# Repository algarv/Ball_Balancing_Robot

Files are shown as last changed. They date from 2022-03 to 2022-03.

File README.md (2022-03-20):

# Ball_Balancing_Robot

For my winter quarter independent study project, set out to build my own version of a BallBot, a dynamically stable / statically unstable robot. I am designed my bot from CAD to control algorithm, utilizing 3D printing, laser cutting, and C programming on an RP2040 microcontroller. 

final

https://youtu.be/7S1Z_5BLMUo

### Hardware
* RP2040 ThingPlus Microcontroller 
* MPU6050 Stepper Motor Driver (x3)
* A4988 Stepper Motor Driver (x3)
* NEMA 17 Stepper Motors (x3) 

### Chassis Design
The chassis was built with a combination of 3D printed components and laser cut plates.
In addition to self-fabricated pieces, the following components were purchased:
* 2-3/8" Diameter x 1" Wide Omnidirectional Wheels from McMaster-Carr (https://www.mcmaster.com/2289T514/)
* 4-40 Aluminum threaded rodd
* 4-40 Hex Nuts
* 4-40 Hex Screws
* Rubber Washers (0.190" ID, 1/2" OD)

<p float="left">
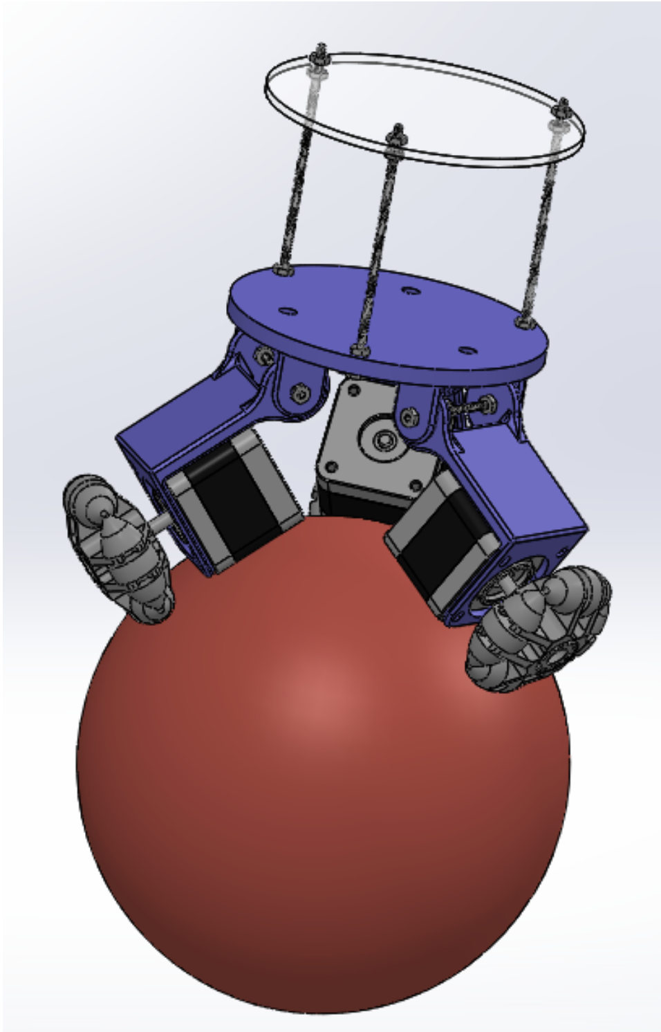
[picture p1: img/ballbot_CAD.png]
  
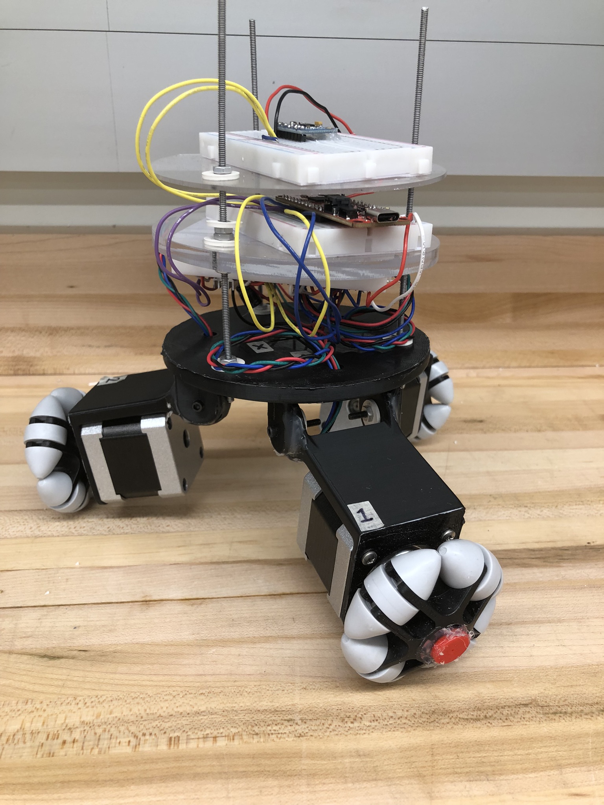
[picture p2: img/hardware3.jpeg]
   
</p>

### Electronics Assembly
The circuit was spread across three small breadboards, with an external power supply providing 8.5 volts to the motor drivers and a laptop providing 3.3V to the micocontroller. In future iteration, the power source would ideally be a battery with a volage regulator supplying both motor and logic power.

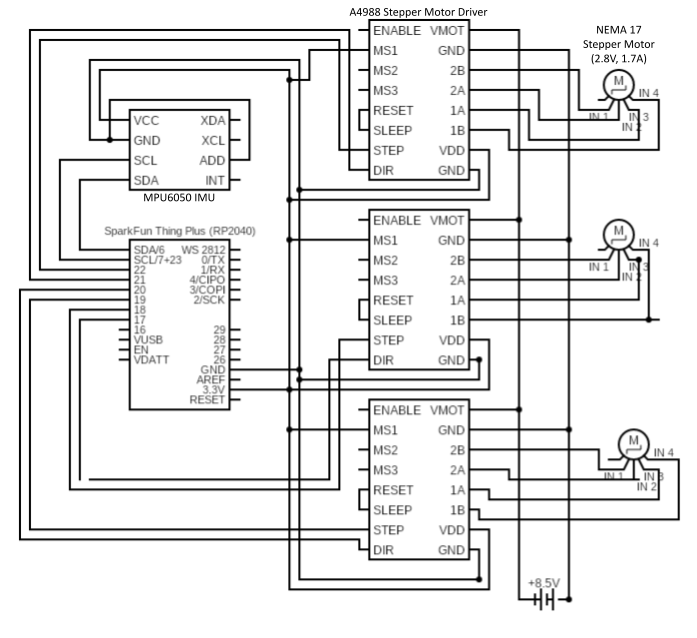
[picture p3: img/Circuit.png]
Circuit


### Controls
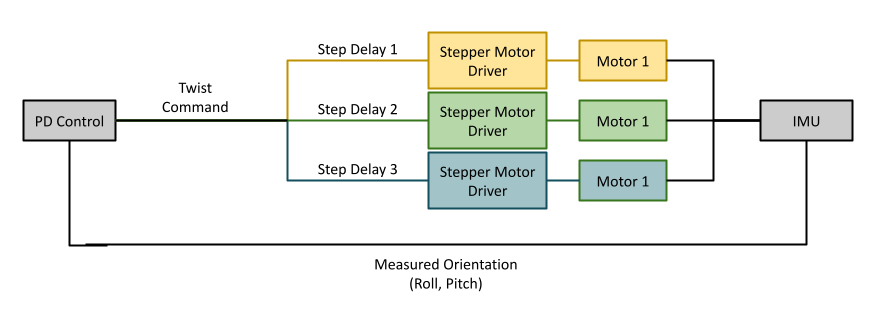
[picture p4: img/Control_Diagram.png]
Controls


The provided code demonstrates a PD feedback loop in which the IMU samples accelerometer and gyroscope data, uses a rolling average followed by a complimentary filter to calculate roll and pitch, and then generates a desired x and y velocity based on the deviation from 0. The IMU is initially calibrated such that 0 pitch and 0 roll can be considered a stable, upright system. The controll loop runs on a 500 Hz timer with the IMU sampled every 100 ms. The optimal Kp and Kd were found to be .29 and .27 respectively, however, these will likely vary depending on a variety of factors unique to each build. 

The software is based on the Pico SDK, find the documentation and instructions to get started here:
https://datasheets.raspberrypi.com/pico/raspberry-pi-pico-c-sdk.pdf

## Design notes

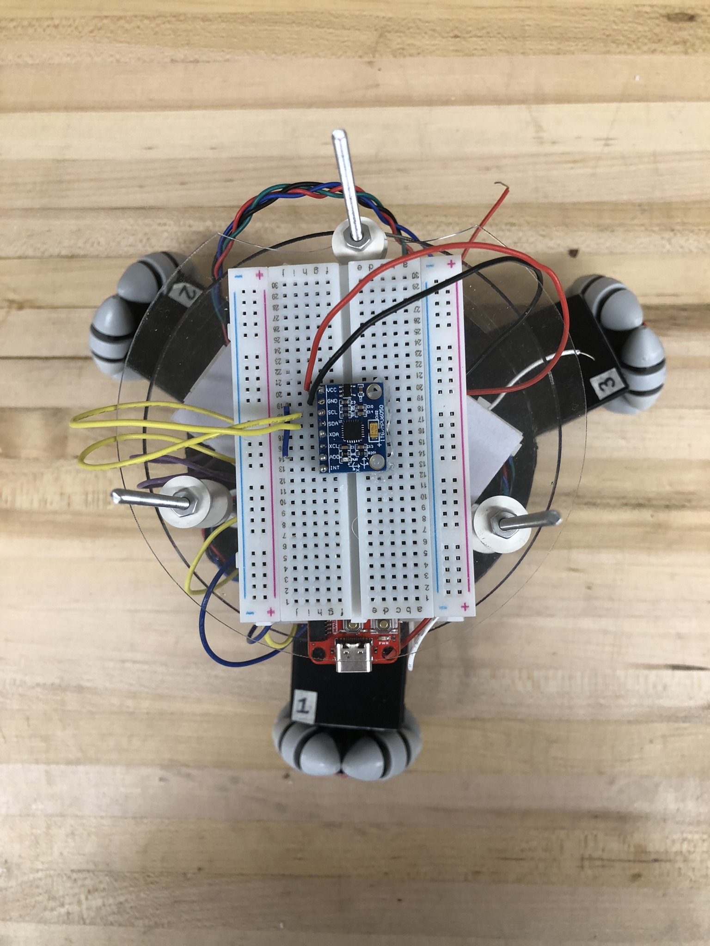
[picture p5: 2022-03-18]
img/hardware2.jpeg

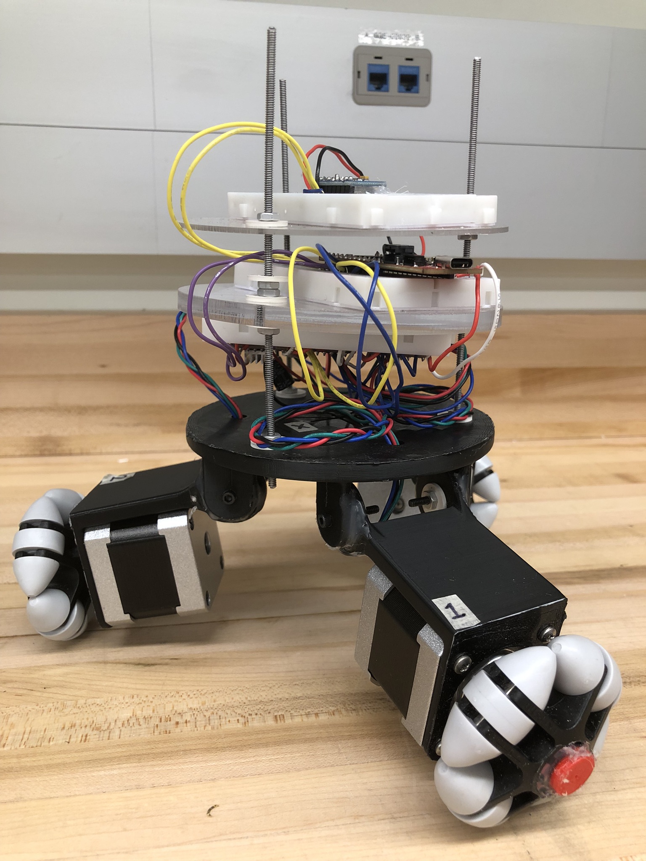
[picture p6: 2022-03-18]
img/hardware1.jpeg

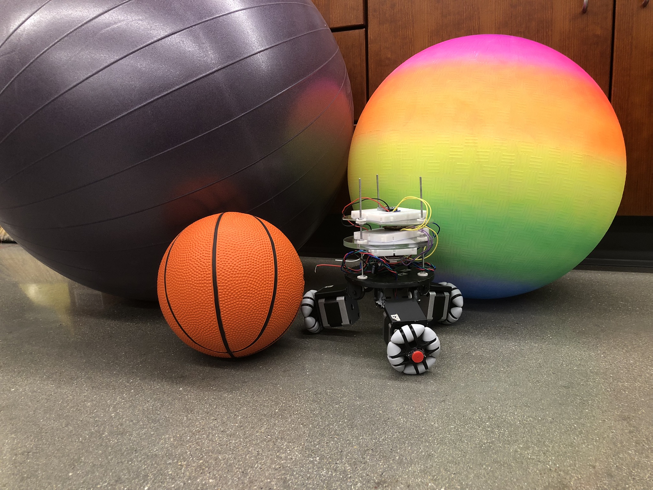
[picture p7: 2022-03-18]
img/cover_photo.jpeg

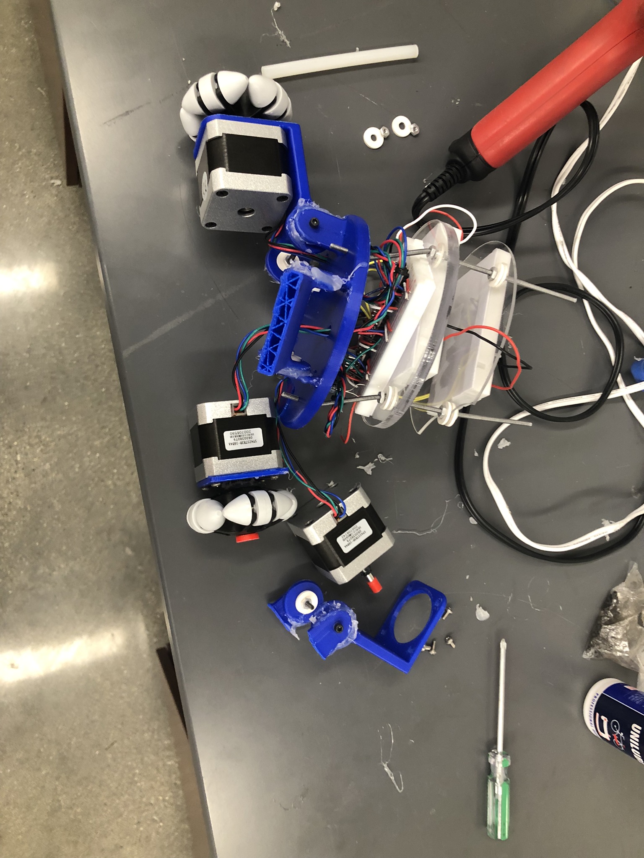
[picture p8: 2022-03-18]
img/carnage.jpeg

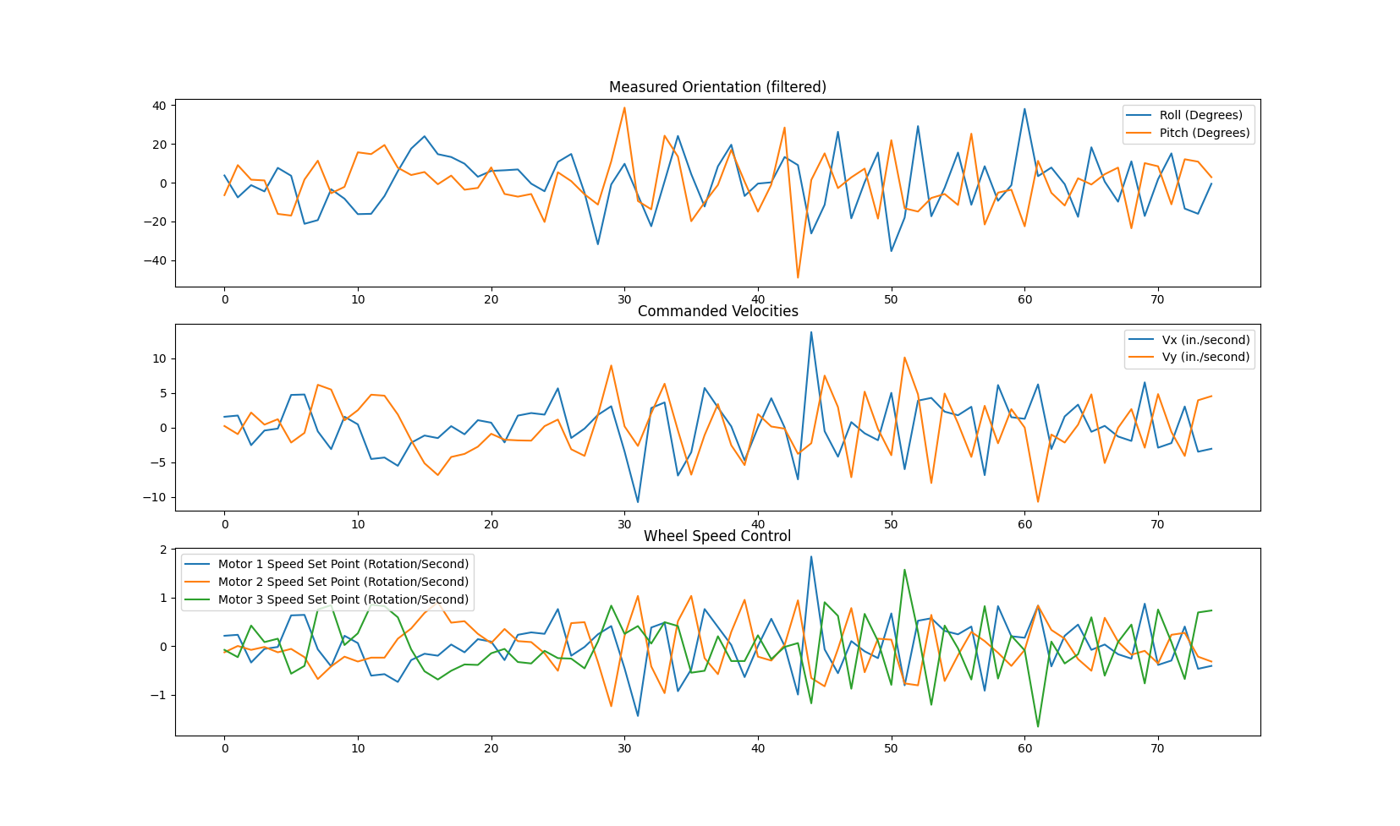
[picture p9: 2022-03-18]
img/assisted_balancing.png

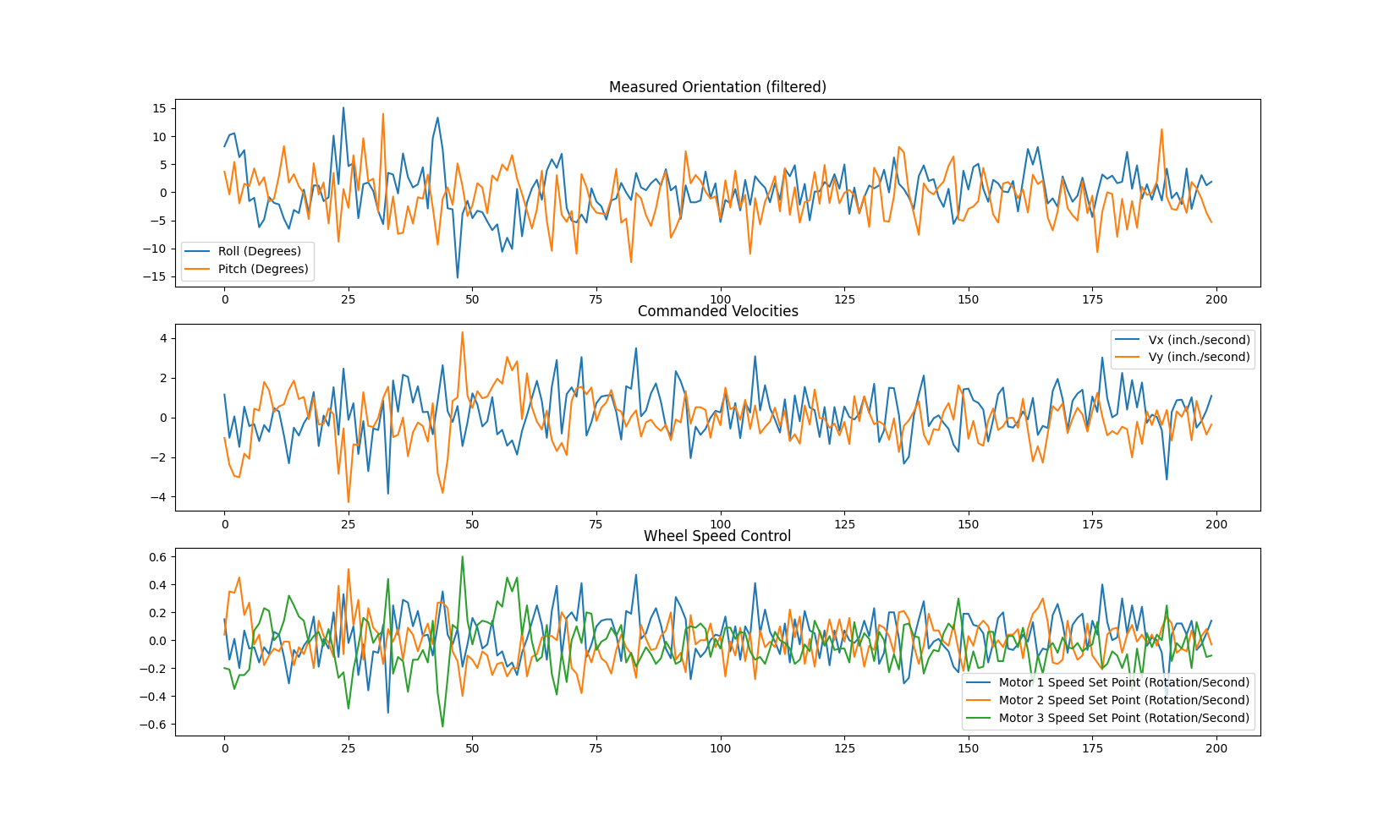
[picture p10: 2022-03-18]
img/baseline.png

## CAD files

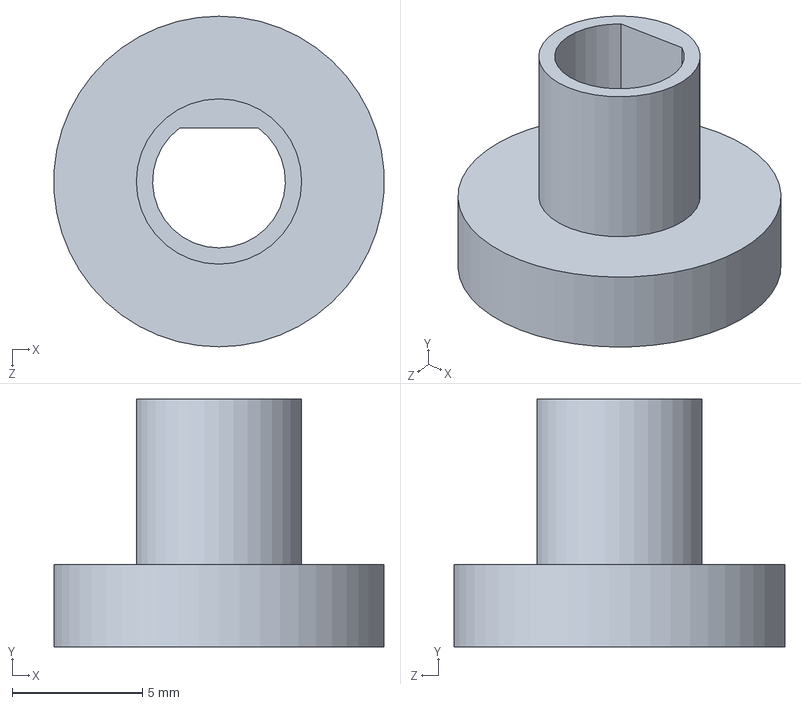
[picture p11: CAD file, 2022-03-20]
CAD/motor_pin_2.SLDPRT
12.7 x 9.53 x 12.7 mm

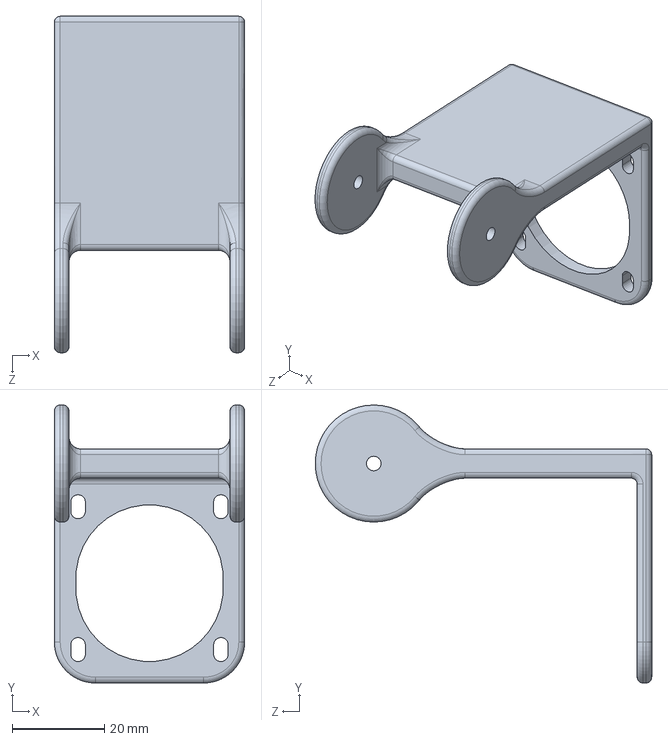
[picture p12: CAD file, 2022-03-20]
CAD/motor_housing_v2.SLDPRT
41.3 x 60.3 x 73.0 mm

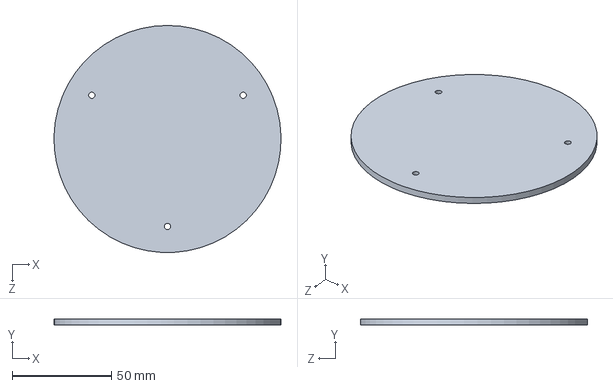
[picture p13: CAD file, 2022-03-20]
CAD/body_plate.SLDPRT
114.2 x 3.17 x 114.3 mm

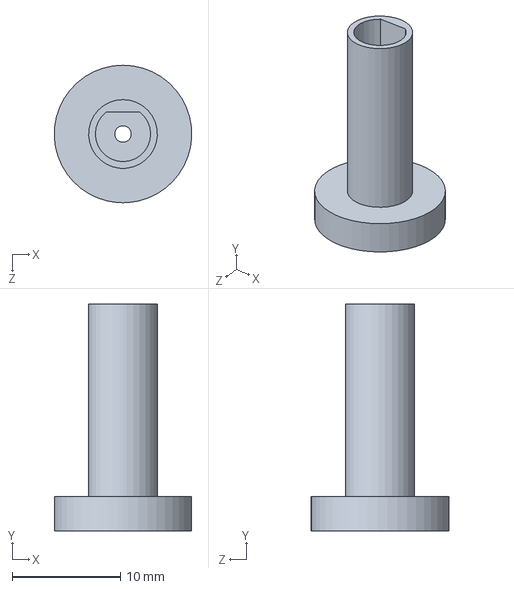
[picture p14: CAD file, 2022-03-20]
CAD/motor_pin.SLDPRT
12.7 x 21.0 x 12.7 mm

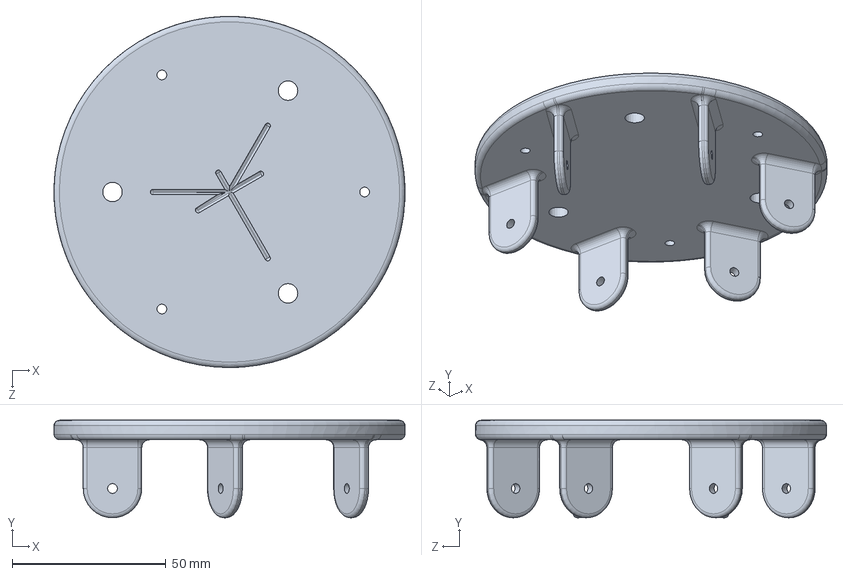
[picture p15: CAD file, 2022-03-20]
CAD/motor_plate.SLDPRT
114.3 x 31.8 x 114.3 mm

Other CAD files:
CAD/motor_housing_v2.STL
CAD/motor_pin.STL
CAD/motor_pin_2.STL
CAD/motor_plate.STL

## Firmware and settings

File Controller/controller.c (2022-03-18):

#include <stdio.h>
#include "pico/stdlib.h"
#include "hardware/gpio.h"
#include "hardware/irq.h"
#include <math.h>
#include <time.h>
#include "IMU.h"

/*Robot chassis specifications
*/
#define d 2.25 //distance from center of the chasis to the wheel
#define r 1.1875 // radius of the wheel
#define PI 3.14159265

/*STEP MULTIPLIER 
/ Determined by driver configuration (see driver wiring diagram)
*/
#define Step3_Size .5
#define Step2_Size .5
#define Step1_Size .5

/* TIMER CONFIGURATION
/  TIMER (ms) sets the time between of motor callbacks
/  dt (ms) sets the loop sleep time, which allows the timer to run.
/  Experimentally, the control is optimal when TIMER * dt = 200
/  Together, dt and TIMER are parameters that trade off between controller sensitivity
/  and the wheels' maximum rotational velocity. 
*/
#define TIMER 2
#define dt 100

/* PID CONTROL  
/  Convert error in roll and pitch (any measurement above 0)
/  to twist commands.
/  Inputs: Roll, Pitch (degrees)
/  Outputs: Vx, Vy (in./sec.)
*/
#define Kp .29 //.29 //0.69
#define Kd .27 //.27 //0.35 //0.04 //.25 //.3 //.3
#define Ki 0

/*Microcontroller configuration*/
const int stepPin3 = 19;
const int dirPin3 = 20;

const int stepPin1 = 22;
const int dirPin1 = 21;

const int stepPin2 = 18;
const int dirPin2 = 17;

/* Global Variables for motor controll */
float rps_motor1;
float rps_motor2;
float rps_motor3;

int motor1_count = 0;
int motor2_count = 0;
int motor3_count = 0;
int print_count = 0;

float delay1;
float delay2;
float delay3;

float e_int_vx = 0;
float saved_e_vx = 0;
float e_int_vy = 0;
float saved_e_vy = 0;

int dir1;
int dir2;
int dir3;

double roll_acc;
double pitch_acc;
double roll_gyro;
double pitch_gyro;

struct Twist{
    float vx;
    float vy;
    float w;
}; //in. per sec.

typedef struct Twist Twist;

Twist twist_cmd;

/* Global variables for measurement updates*/
IMU_Data raw_IMU;
IMU_Data saved_IMU[4];
IMU_Data filtered_IMU;
Orientation calibration;
Orientation calced_RPY;
Orientation saved_RPY;

/* Helper function prototypes */
Twist get_twist(Orientation RPY);
IMU_Data filter_IMU(IMU_Data IMU);
void update_wheels(Twist twist);
void update_motors();
bool motor_callback(void);

/* filter_IMU
/  Calculates a rolling average for the IMU measurement 
*/
IMU_Data filter_IMU(IMU_Data IMU){
    IMU_Data filtered;
    IMU_Data sum;

    sum.accelX =  IMU.accelX;
    sum.accelY = IMU.accelY;
    sum.accelZ = IMU.accelZ;
    sum.gyroX = IMU.gyroX;
    sum.gyroY = IMU.gyroY;
    sum.gyroZ = IMU.gyroZ;

    for (int i=0; i<3; i++){
        sum.accelX +=  saved_IMU[i].accelX;
        sum.accelY += saved_IMU[i].accelY;
        sum.accelZ += saved_IMU[i].accelZ;
        sum.gyroX += saved_IMU[i].gyroX;
        sum.gyroY += saved_IMU[i].gyroY;
        sum.gyroZ += saved_IMU[i].gyroZ;
    }

    saved_IMU[0] = IMU;
    for (int i=0; i<3; i++){
        saved_IMU[i+1] = saved_IMU[i];
    }

    filtered.accelX = sum.accelX/4;
    filtered.accelY = sum.accelY/4;
    filtered.accelZ = sum.accelZ/4;
    filtered.gyroX = sum.gyroX/4;
    filtered.gyroY = sum.gyroY/4;
    filtered.gyroZ = sum.gyroZ/4;

    return filtered;
}

/* get_twist
/  The primary PID controller. 
/  Receives the calculated orientation and outputs a twist command using the set gains 
/  and assuming a set-point of 0 roll and 0 pitch.
*/
Twist get_twist(Orientation RPY){
    Twist twist_cmd;

    //printf("Inputs -- yaw: %6.2f, Kp: %6.2f",RPY.yaw, Kp);
    float e_vx = 0 - RPY.pitch;
    e_int_vx += e_vx;

    float e_vy = 0 - RPY.roll;
    e_int_vy += e_vy;

    twist_cmd.vx = Kp*e_vx + Kd*(saved_e_vx-e_vx) + Ki*e_int_vx;
    twist_cmd.vy = Kp*e_vy + Kd*(saved_e_vy-e_vy) + Ki*e_int_vy;
    twist_cmd.w = 0;


    //printf("%6.2f, %6.2f",twist_cmd.vx,twist_cmd.vy);

    // printf("Vx: %6.2f Vy: %6.2f \n",twist_cmd.vx,twist_cmd.vy);

    //saved_RPY = RPY;
    saved_e_vx = e_vx;
    saved_e_vy = e_vy;

    return twist_cmd;
}

/* update_wheels
/  Calculates the motor step rate starting with the commanded twist.
/  Wheel speed equation reference: "Modern Robotics: Mechanics, Planning, and Control," Kevin M. Lynch and Frank C. Park, Cambridge University Press, 2017,
*/
void update_wheels(Twist twist){

/*
    u1 = (-d*w + vx)/r
    u2 = (-d*w - vx/2 + vy*-sin(pi/3))/r
    u3 = (-d*w - vx/2 + vy*sin(pi/3))/r
*/

    rps_motor1 = ((-1*d*twist.w + twist.vx)/r)/(2*PI);
    rps_motor2 = ((-1*d*twist.w - twist.vx/2 + twist.vy*-sin(PI/3))/r)/(2*PI);
    rps_motor3 = ((-1*d*twist.w - twist.vx/2 + twist.vy*sin(PI/3))/r)/(2*PI);

    delay1 = (1 / (rps_motor1 * 200)); // x rotations/sec * 200 steps/rotation * 1 sec / 1000 ms
    delay2 = (1 / (rps_motor2 * 200));
    delay3 = (1 / (rps_motor3 * 200));

    if (delay1 < 0){
        delay1 = delay1 * -1.0;
    }
    if (delay2 < 0){
        delay2 = delay2 * -1.0;
    }
    if (delay3 < 0){
        delay3 = delay3 * -1.0;
    }

    delay1 *= Step1_Size;
    delay2 *= Step2_Size;
    delay3 *= Step3_Size;

    if (delay1 < TIMER){
        delay1 = TIMER;
    }
    if (delay2 < TIMER){
        delay2 = TIMER;
    }
    if (delay3 < TIMER){
        delay3 = TIMER;
    }

    // if ((delay1 - saved_delay1)/saved_delay1 > 1.00 || ((delay1 - saved_delay1)/saved_delay1 < -1.00)) {
    //     delay1 = saved_delay1;
    // }

    // if ((delay2 - saved_delay2)/saved_delay2 > 1.00 || ((delay2 - saved_delay2)/saved_delay2 < -1.00)) {
    //     delay2 = saved_delay2;
    // }

    // if ((delay3 - saved_delay3)/saved_delay3 > 1.00 || ((delay3 - saved_delay3)/saved_delay3 < -1.00)) {
    //     delay3 = saved_delay3;
    // }

    // saved_delay1 = delay1;
    // saved_delay2 = delay2;
    // saved_delay3 = delay3;

    // counts1 = floor(delay1 / TIMER);
    // counts2 = floor(delay2 / TIMER);
    // counts3 = floor(delay3 / TIMER);

    // print_count++; //Use a print count to slow down print speed and increase legibility
    // if (print_count == 1000/250){
    printf("%6.2f, %6.2f, %6.2f, %6.2f, %6.2f, %6.2f, %6.2f, %6.2f", rps_motor1, rps_motor2, rps_motor3, twist_cmd.vy, twist_cmd.vx, calced_RPY.roll, calced_RPY.pitch, calced_RPY.yaw);
        print_count = 0;
    // }
}

/* motor_callback
/  The function paced by TIMER to step each motor, using a polling algorithm to the number 
/  of timer fires to the calculated step delay. 
*/
bool motor_callback(void){
    
    motor1_count++;
    motor2_count++;
    motor3_count++;

    if((delay1 - motor1_count * TIMER) < .0001){//
        // if (delay1 < 50){
        gpio_put(stepPin1,1);
        // }
        motor1_count = 0;
    }

    if((delay2 - motor2_count * TIMER) < .0001){//
        // if (delay2 < 50){
        gpio_put(stepPin2,1);
        // }
        motor2_count = 0;
    }

    if((delay3 - motor3_count * TIMER) < .0001){
        // if (delay3 < 50){
        gpio_put(stepPin3,1);
        // }
        motor3_count = 0;
    }

    gpio_put(stepPin1,0);
    gpio_put(stepPin2,0);
    gpio_put(stepPin3,0);

    return true;
}

/* update_motors
/  The main control loop organize each step to update motor controlls from the measurement values
*/
void update_motors(){
        
        raw_IMU = read_IMU();
        filtered_IMU = filter_IMU(raw_IMU);
        
        calced_RPY = calc_RPY(filtered_IMU, calibration, .250);

        twist_cmd = get_twist(calced_RPY);
        
        update_wheels(twist_cmd);

        if (rps_motor1 < 0){
            gpio_put(dirPin1,0);
        }
        else{
            gpio_put(dirPin1,1);
        }

        if (rps_motor2 < 0){
            gpio_put(dirPin2,0);
        }
        else{
            gpio_put(dirPin2,1);
        }

        if (rps_motor3 < 0){
            gpio_put(dirPin3,0);
        }   
        else{
            gpio_put(dirPin3,1);
        } 

}


int main()
{
    stdio_init_all();

    gpio_init(stepPin1);
    gpio_init(dirPin1);
    gpio_init(stepPin2);
    gpio_init(dirPin2);
    gpio_init(stepPin3);
    gpio_init(dirPin3);

    gpio_set_dir(stepPin1, GPIO_OUT);
    gpio_set_dir(dirPin1, GPIO_OUT);
    gpio_set_dir(stepPin2, GPIO_OUT);
    gpio_set_dir(dirPin2, GPIO_OUT);
    gpio_set_dir(stepPin3, GPIO_OUT);
    gpio_set_dir(dirPin3, GPIO_OUT);

    IMU_init();

    calibration = calibrate_IMU();
    saved_IMU[0] = read_IMU(calibration);
    saved_IMU[1] = read_IMU(calibration);
    saved_IMU[2] = read_IMU(calibration);
    saved_IMU[3] = read_IMU(calibration);

    delay1 = 1000.0;
    delay2 = 1000.0;
    delay3 = 1000.0;
    
    /* Timer Set-Up */
    struct repeating_timer motor_timer;
    add_repeating_timer_ms(-1*TIMER, motor_callback, NULL, &motor_timer);
    
    /* CONTROL LOOP */
    while(true){
        update_motors();
        sleep_ms(dt); 
    }
}

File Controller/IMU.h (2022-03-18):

#ifndef IMU_test__H__
#define IMU_test__H__

#include <stdio.h>
#include <math.h>
#include <stdint.h>
#include "pico/stdlib.h"
#include "hardware/i2c.h"

#define I2C_PORT i2c1
#define CONFIG 0x1A
#define SMPLRT_DIV 0x19 // A DIVIDER FOR SCALING THE GYRO SAMPLE RATE: set to 0 for max
#define GYRO_CONFIG 0x1B
#define ACCEL_CONFIG 0x1C
#define PWR_MGMT_1 0x6B // Device defaults to the SLEEP mode
#define ACCEL_X 0x3B
#define ACCEL_Y 0x3D
#define ACCEL_Z 0x3F
#define GYRO_X 0x43
#define GYRO_Y 0x45
#define GYRO_Z 0x47
#define ADDR 0x68

struct IMU_Data
{
    float accelX;
    float accelY;
    float accelZ;
    float gyroX;
    float gyroY;
    float gyroZ; 
};

typedef struct IMU_Data IMU_Data;

struct Orientation{
    float roll;
    float pitch;
    float yaw;
};

typedef struct Orientation Orientation;

void IMU_init(void);
Orientation calibrate_IMU(void);
IMU_Data read_IMU();
Orientation calc_RPY(IMU_Data IMU, Orientation calib, double dt);

double pitch_gyro = 0;
double roll_gyro = 0;
double pitch_acc = 0;
double roll_acc = 0;

void IMU_init(void){
    i2c_init(I2C_PORT, 400 * 1000);
    gpio_set_function(6, GPIO_FUNC_I2C);
    gpio_set_function(7, GPIO_FUNC_I2C);
    gpio_pull_up(6);
    gpio_pull_up(7);

    sleep_ms(1000);

    uint8_t reg = 0x1E;
    uint8_t chipID[1];
    uint8_t Ascale = 0;     // AFS_2G, AFS_4G, AFS_8G, AFS_16G
    uint8_t Gscale = 0; // GFS_250DPS, GFS_500DPS, GFS_1000DPS, GFS_2000DPS

    i2c_write_blocking(I2C_PORT, ADDR, &reg, 1, true);
    i2c_read_blocking(I2C_PORT, ADDR, chipID, 1, false);

    uint8_t data[2];
    data[0] = PWR_MGMT_1;
    data[1] = 0x00;
    i2c_write_blocking(I2C_PORT, ADDR, data, 2, true);

    data[0] = PWR_MGMT_1;
    data[1] = 0x01;
    i2c_write_blocking(I2C_PORT, ADDR, data, 2, true);

    data[0] = CONFIG;
    data[1] = 0x00;
    i2c_write_blocking(I2C_PORT, ADDR, data, 2, true);

    data[0] = SMPLRT_DIV;
    data[1] = 0x00;
    i2c_write_blocking(I2C_PORT, ADDR, data, 2, true);

    int c = i2c_read_blocking(I2C_PORT, ADDR, GYRO_CONFIG, 1, false);

    data[0] = GYRO_CONFIG;
    data[1] = c & ~0xE0;
    i2c_write_blocking(I2C_PORT, ADDR, data, 2, true);

    data[0] = GYRO_CONFIG;
    data[1] = c & ~0x18;
    i2c_write_blocking(I2C_PORT, ADDR, data, 2, true);

    data[0] = GYRO_CONFIG;
    data[1] = c | Gscale << 3;
    i2c_write_blocking(I2C_PORT, ADDR, data, 2, true);

    c = i2c_read_blocking(I2C_PORT, ADDR, ACCEL_CONFIG, 1, false);

    data[0] = ACCEL_CONFIG;
    data[1] = c & ~0xE0;
    i2c_write_blocking(I2C_PORT, ADDR, data, 2, true);

    data[0] = ACCEL_CONFIG;
    data[1] = c & ~0x18;
    i2c_write_blocking(I2C_PORT, ADDR, data, 2, true);

    data[0] = ACCEL_CONFIG;
    data[1] = c | Ascale << 3;
    i2c_write_blocking(I2C_PORT, ADDR, data, 2, true);
}

Orientation calibrate_IMU(void){
    // IMU_Data IMU_Calibration;
    Orientation RPY_Calibration;

    printf("Calibrating IMU. Place robot on a flat surface.\n");

    // IMU_Data null_calibration;
    Orientation null_calibration;
    null_calibration.roll = 0.0;
    null_calibration.pitch = 0.0;
    null_calibration.pitch = 0.0;

    float accelX[5000], accelY[5000], accelZ[5000], gyroX[5000], gyroY[5000], gyroZ[5000];
    float accelX_avg = 0.0, accelY_avg = 0.0, accelZ_avg = 0.0, gyroX_avg = 0.0, gyroY_avg = 0.0, gyroZ_avg = 0.0;
    float roll_avg = 0.0, pitch_avg = 0.0, yaw_avg = 0.0;

    for(int i=0; i<=5000; i++){
        IMU_Data data = read_IMU();
        Orientation RPY = calc_RPY(data, null_calibration, .250);

        roll_avg += RPY.roll;
        pitch_avg += RPY.pitch;
        yaw_avg += RPY.yaw;
    }

    RPY_Calibration.roll = roll_avg/5000.0;
    RPY_Calibration.pitch = pitch_avg/5000.0;
    RPY_Calibration.yaw = yaw_avg/5000.0;

    return RPY_Calibration;
    // return IMU_Calibration;
}

Orientation calc_RPY(IMU_Data IMU, Orientation calib, double dt){
    Orientation RPY;

    roll_acc = 180 * atan(IMU.accelY/sqrt(IMU.accelX*IMU.accelX + IMU.accelZ*IMU.accelZ))/M_PI; //180*atan2(IMU.accelX,IMU.accelZ)/M_PI;
    pitch_acc = 180 * atan(IMU.accelX/sqrt(IMU.accelY*IMU.accelY + IMU.accelZ*IMU.accelZ))/M_PI; //180*atan2(IMU.accelY,IMU.accelZ)/M_PI;

    roll_gyro = IMU.gyroY * dt;  // Angle around the Y-axis
    pitch_gyro = IMU.gyroX * dt; // Angle around the X-axis

    RPY.roll = 0.7 * (RPY.roll - roll_gyro) + 0.3 * roll_acc;
    RPY.pitch = 0.7 * (RPY.pitch + pitch_gyro) + 0.3 * pitch_acc;
    RPY.yaw = 180 * atan(IMU.accelZ/sqrt(IMU.accelX*IMU.accelX + IMU.accelY*IMU.accelY))/M_PI;

    RPY.roll -= calib.roll;
    RPY.pitch -= calib.pitch;
    RPY.yaw -= calib.yaw;

    return RPY;
}


IMU_Data read_IMU(){

    IMU_Data data;

    uint8_t reg_accel = ACCEL_X;
    uint8_t reg_gyro = GYRO_X;
    uint8_t accel[6];
    uint8_t gyro[6];
    int16_t accelX, accelY, accelZ;
    int16_t gyroX, gyroY, gyroZ;

    i2c_write_blocking(I2C_PORT, ADDR, &reg_accel, 1, true);
    i2c_read_blocking(I2C_PORT, ADDR, accel, 6, false);

    //(((vh << 8) & 0xff00) | (vl & 0x00ff)) & 0xffff;
    accelX = (((accel[0]<<8) & 0xff00) | (accel[1] & 0x00ff)) & 0xffff;
    accelY = (((accel[2]<<8) & 0xff00) | (accel[3] & 0x00ff)) & 0xffff;
    accelZ = (((accel[4]<<8) & 0xff00) | (accel[5] & 0x00ff)) & 0xffff;

    // Scale to +/- 2g
    data.accelX = (2.0 / 32767.0 * accelX); // - calibration.accelX;
    data.accelY = (2.0 / 32767.0 * accelY); // - calibration.accelY;
    data.accelZ = (2.0 / 32767.0 * accelZ); // - calibration.accelZ;

    i2c_write_blocking(I2C_PORT, ADDR, &reg_gyro, 1, true);
    i2c_read_blocking(I2C_PORT, ADDR, gyro, 6, false);

    gyroX = (((gyro[0]<<8) & 0xff00) | (gyro[1] & 0x00ff)) & 0xffff;
    gyroY = (((gyro[2]<<8) & 0xff00) | (gyro[3] & 0x00ff)) & 0xffff;
    gyroZ = (((gyro[4]<<8) & 0xff00) | (gyro[5] & 0x00ff)) & 0xffff;

    // Scale to +/- 500 deg/s
    data.gyroX = (500.0 / 32767.0 * gyroX); // - calibration.gyroX;
    data.gyroY = (500.0 / 32767.0 * gyroY); // - calibration.gyroY;
    data.gyroZ = (500.0 / 32767.0 * gyroZ); // - calibration.gyroZ;

    return data;
}

#endif
